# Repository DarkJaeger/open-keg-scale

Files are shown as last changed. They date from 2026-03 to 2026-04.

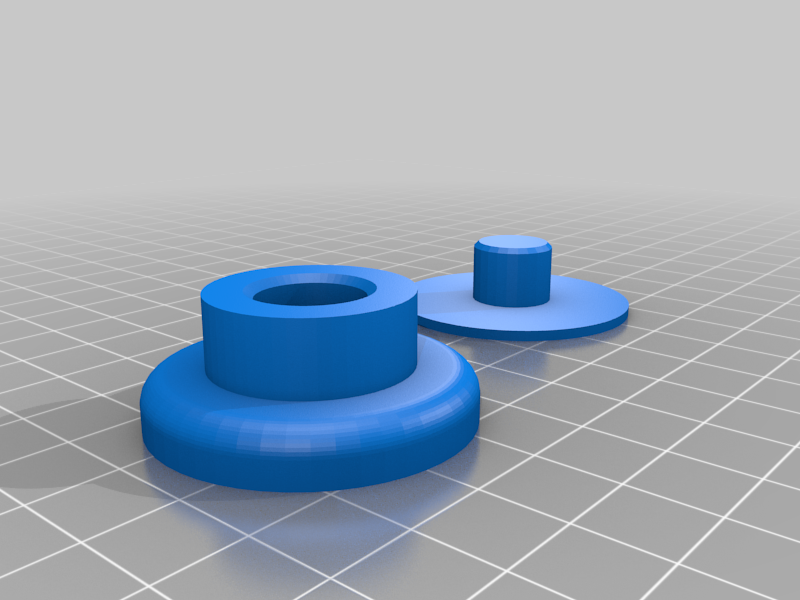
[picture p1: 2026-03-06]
open_keg_scale/3d printer files/images/16e5dbe0-ccde-49db-850b-022b4e718a14.png

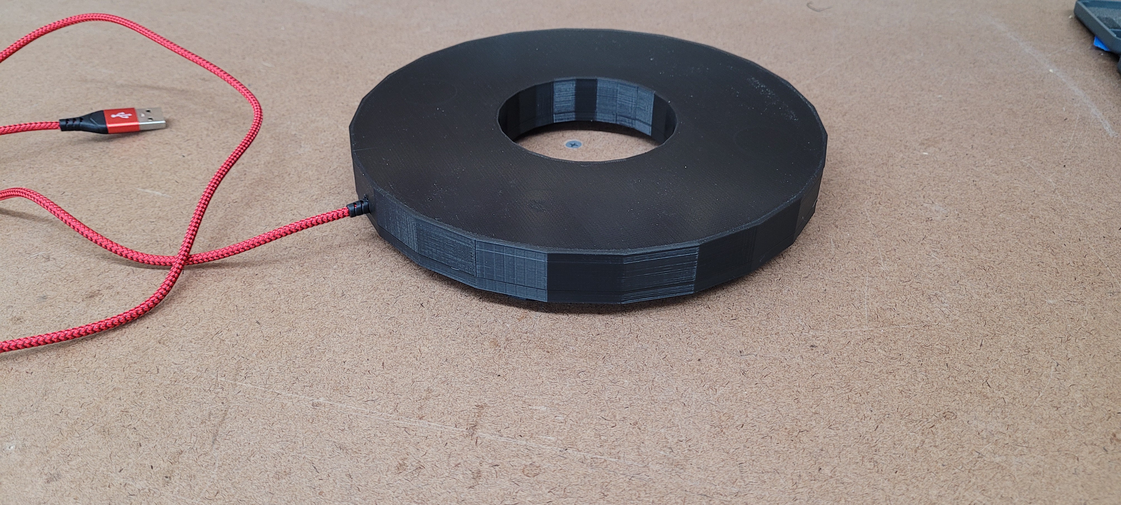
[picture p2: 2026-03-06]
open_keg_scale/3d printer files/images/8abd5797-2a0b-4ab6-b557-2e7c1733cc50.jpg

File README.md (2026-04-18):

<a href="https://www.buymeacoffee.com/LocutusOFB">Buy Me A Coffee</a>

🍺 Open Keg Scale

DIY WiFi-enabled keg scale hardware designed to work with
open-plaato-keg

This repo includes two complete scale designs:

🍻 Standard Keg Scale (serving / monitoring)
🔄 Transfer Keg Scale (closed-loop transfers)
🚀 Overview

Open Keg Scale provides real-time weight data from your kegs and feeds it into open-plaato-keg for:

Remaining volume tracking
Pour detection
Transfer monitoring
Usage analytics

All fully local — no cloud required.

⚖️ Scale Types
🍻 Standard Keg Scale (Serving)
6

Designed for kegerators and serving setups.

Use Cases:

Track remaining beer in keg
Monitor pours in real time
Integrate with dashboards / Home Assistant

Features:

Stable 4-load-cell platform
Continuous weight monitoring
Pour detection via weight delta
🔄 Transfer Keg Scale (Closed Transfer)
6

Designed for closed-loop transfers from fermenter → keg.

Use Cases:

Monitor fill progress during transfer
Prevent overfilling
Track exact transferred volume

Features:

Compact / targeted design
High accuracy for fill tracking
Real-time feedback during transfer
🧰 What’s Included
✅ STL files for both scale designs
✅ ESP32-based firmware examples
✅ Wiring guidance
✅ Integration with open-plaato-keg
🏗️ Hardware Requirements
ESP32 (recommended)
HX711 load cell amplifier
Load cells (typically 4x 50kg)
5V power supply
Optional OLED display
3D printed parts (included in /stl)
🖨️ 3D Printed Parts

All required STL files are included:

Standard scale platform
Transfer scale platform
Mounting hardware / enclosures

Print in PLA or PETG depending on environment

🔌 Wiring Overview
Load Cells → HX711
HX711 → ESP32 (DT + SCK)
Optional OLED → I2C
⚙️ Firmware

Recommended: ESPHome

sensor:
  - platform: hx711
    name: "Keg Weight"
    dout_pin: GPIO21
    clk_pin: GPIO22
    gain: 128
    update_interval: 1s
🔗 Integration

This hardware feeds data into:

👉 open-plaato-keg

Supports:

REST API
MQTT
Home Assistant bridge
📡 Data Flow
[Load Cells] → [HX711] → [ESP32] → [WiFi] → [open-plaato-keg]
⚖️ Calibration
Tare empty scale
Add known weight
Adjust calibration factor
Save configuration
🧪 Roadmap
 Auto-discovery in open-plaato-keg
 OTA updates
 Battery-powered version
 Multi-scale controller
🤝 Related Project
open-plaato-keg – backend + dashboard
💡 Pro Tips
Use 4 load cells for stability
Keep HX711 wiring short
Calibrate with realistic loads
Solid mounting = better accuracy

Corny keg scale (Plaato) by FloppyKnockers on Thingiverse: https://www.thingiverse.com/thing:6007574

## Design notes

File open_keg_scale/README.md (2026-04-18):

# Open Keg Scale – Firmware

Arduino sketch for **Wemos D1 Mini (ESP8266)** + **HX711** + **4 × 50 kg half-bridge load cells**.  
Reports keg weight / volume to [open-plaato-keg](https://github.com/DarkJaeger/open-plaato-keg) using the Blynk binary TCP protocol.
After the initial USB flash, it also supports **Arduino OTA** updates over WiFi.

---

## Parts

| Part | Notes |
|---|---|
| Wemos D1 Mini | ESP8266, 4 MB flash |
| HX711 breakout | Any common board |
| 4 × 50 kg half-bridge load cell | The ones that came with the scale |

---

## Wiring

### Load Cells → HX711

Wire the four half-bridge cells as a single **full Wheatstone bridge** for best accuracy.  
Each cell has three wires: **RED** (E+), **BLACK** (E−), **WHITE** (signal).

```
Cell A (front-left)   RED  ──┐
Cell B (front-right)  RED  ──┤──→  HX711 E+
Cell C (back-right)   RED  ──┤
Cell D (back-left)    RED  ──┘

Cell A (front-left)   BLACK──┐
Cell B (front-right)  BLACK──┤──→  HX711 E−
Cell C (back-right)   BLACK──┤
Cell D (back-left)    BLACK──┘

Cell A (front-left)   WHITE──┐
Cell C (back-right)   WHITE──┘──→  HX711 A+    (diagonal pair)

Cell B (front-right)  WHITE──┐
Cell D (back-left)    WHITE──┘──→  HX711 A−    (other diagonal pair)
```

> **Why diagonals?** Opposite corners of a platform scale flex in the same
> direction when loaded, so wiring them to the same signal leg produces
> additive output and cancels common-mode errors.

### HX711 → Wemos D1 Mini

| HX711 | Wemos D1 Mini |
|---|---|
| VCC | 3V3 |
| GND | GND |
| DT | D6 (GPIO 12)  |
| SCK | D5 (GPIO 14)  |

### Button / LED

| Signal | Pin |
|---|-----|
| Tare / reset button | D3 (GPIO 0) – built-in FLASH button |
| Status LED | D4 (GPIO 2) – built-in LED (active LOW) |

---

## LED Status

| Pattern | Meaning |
|---|---|
| Fast blink (100 ms) | Connecting to WiFi or Blynk server |
| Medium blink (250 ms) | TCP connected, waiting for auth |
| Slow blink (500 ms) | Fully connected and reporting |
| 3 short flashes | Tare complete |
| 4 short flashes | Calibration saved |

---

## Required Libraries

Install both via **Arduino IDE → Tools → Manage Libraries**:

| Library | Author | Version |
|---|---|---|
| **WiFiManager** | tzapu | ≥ 2.0.17 |
| **HX711 Arduino Library** | Bogdan Necula | ≥ 0.7.5 |

Board: **LOLIN(WEMOS) D1 mini** (under *ESP8266 Boards* – install ESP8266 core via Board Manager if needed).

`ArduinoOTA` comes with the ESP8266 board core, so there is no separate library to install for OTA updates.

---

## First-Time Setup

1. Flash `keg_scale.ino` to the Wemos D1 Mini.
2. On first boot the device creates a WiFi access point named **`KegScale-Setup`**.
3. Connect your phone/laptop to that AP (no password) and browse to `http://192.168.4.1`.
4. Fill in the form:
   - **WiFi SSID & password** – your home network
   - **Plaato Server Host** – IP or hostname of the machine running open-plaato-keg  
     (e.g. `192.168.1.50`)
   - **Server Port** – default `1234`
   - **Auth Token** – the 32-character hex token from the open-plaato-keg web UI
   - **Calibration Factor** – optional, if you already know the factor for this scale
   - **Max Keg Volume (L)** – e.g. `19` for a standard Cornelius keg
   - **Beer Name** – displayed in the UI
5. Click **Save**. The device reboots and connects automatically.

> To reconfigure, hold the FLASH button for **4+ seconds** – this wipes the
> saved WiFi credentials and restarts the setup portal.
> On enclosed units, you can also use the local web UI and click
> **Reset WiFi / Enter Setup Mode** to wipe credentials and return to
> `KegScale-Setup` without opening the enclosure.

---

## OTA Updates

After the board has been flashed once over USB and joined WiFi successfully, it will advertise an Arduino OTA target on your local network.

- **Hostname:** `keg-scale-<chipid>`
- **Password:** the same 32-character auth token configured for the server

In Arduino IDE:

1. Make sure your computer is on the same network as the keg scale.
2. Wait for the board to boot and connect to WiFi.
3. Open **Tools → Port** and choose the **network port** for `keg-scale-...`.
4. Click **Upload**.
5. When prompted, enter the auth token as the OTA password.

Serial output will show OTA status messages and progress during the update.

### Browser-based OTA

The firmware also serves a simple web page on the device IP:

- **Status page:** `http://<device-ip>/`
- **Firmware upload:** `http://<device-ip>/update`

If an auth token is configured, log in with:

- **Username:** `admin`
- **Password:** the same 32-character auth token

This is the simplest update path when Arduino IDE does not discover the board automatically over the network.

---

## Calibration

The scale ships with a calibration factor of `1.0` (uncalibrated). You must calibrate once before volume readings are accurate.

### Via the server UI (recommended)

1. Remove everything from the scale platform.
2. In the open-plaato-keg web interface, click **Tare**.
3. Place an object of known mass (e.g. a full water bottle, a bag of flour).
4. Enter the mass in **grams** in the *Calibrate with known weight* field and click **Send**.
5. The device saves the new calibration factor to flash.

### Via Serial

1. Open Serial Monitor at 115200 baud.
2. Remove everything from the scale and short-press the FLASH button to tare.
3. Place a known weight; note the raw reading printed on Serial.
4. Use the server UI calibrate command as above, or compute:  
   `cal_factor = raw_value / known_grams`

---

## Virtual Pin Reference

| Pin | Name | Direction | Description |
|-----|---|---|---|
| v48 | percent_of_beer_left | device → server | % of keg remaining |
| v49 | is_pouring | device → server | `"1"` while pouring |
| v51 | amount_left | device → server | Litres remaining |
| v53 | weight_raw | device → server | Total weight in grams |
| v54 | volume_raw | device → server | Liquid volume in L |
| v55 | pour_volume_raw | device → server | Last pour volume (L) |
| v59 | last_pour | device → server | Last pour volume (L) |
| v60 | tare | server → device | Send `"1"` to tare |
| v61 | known_weight_calibrate | server → device | Send grams to calibrate |
| v62 | empty_keg_weight | server → device | `"1"` = capture current; or send grams |
| v64 | beer_name | both | Beer name string |
| v71 | unit | server → device | `"1"`=metric `"2"`=US |
| v75 | measure_unit | server → device | `"1"`=weight `"2"`=volume |
| v76 | max_keg_volume | server → device | Max volume in litres |
| v81 | wifi_signal_strength | device → server | RSSI in dBm |
| v93 | firmware_version | device → server | e.g. `"1.0.0"` |

---

## Protocol Overview

The device speaks the **Blynk classic binary TCP protocol** (not Blynk IoT/v2).

```
Packet:   [cmd:u8][msg_id:u16be][length:u16be][body:bytes]
Response: [0x00  ][msg_id:u16be][status:u16be]            (no body)
```

1. Device connects TCP to `server_host:server_port`.
2. Sends **LOGIN** (cmd=2) with the auth token as body.
3. Server replies with a RESPONSE (status=200) using the same `msg_id`.
4. Device pushes data via **HARDWARE** (cmd=20) commands: body = `"vw\0<pin>\0<value>"`.
5. Device sends **PING** (cmd=6) every 30 s to keep the connection alive.
6. Server can push commands back to the device using HARDWARE write packets.

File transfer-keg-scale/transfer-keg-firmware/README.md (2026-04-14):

# Transfer Keg Firmware
**Platform:** Wemos D1 Mini (ESP8266)  
**Server:** open-plaato-server  
**Companion:** Android app via open-plaato API

---

## Wiring

### HX711 → D1 Mini
| HX711 | D1 Mini | GPIO  |
|---|---|---|
| DOUT  | D5 | 14 |
| SCK | D6 | 12 |
| VCC | 5V | — |
| GND | GND | — |

### OLED (SSD1306 128×64) → D1 Mini
| OLED | D1 Mini | GPIO |
|---|---|---|
| SDA  | D2 | 4 |
| SCL  | D1 | 5 |
| VCC  | 3.3V | — |
| GND  | GND | — |

### Load Cells → HX711
Wire 4 cells as a Wheatstone bridge:
```
Cell A: E+ → E+,  S+ → A+
Cell B: E+ → E+,  S+ → B+   (opposite corner to A)
Cell C: E- → E-,  S- → A-
Cell D: E- → E-,  S- → B-   (opposite corner to C)
```
Most 4-cell platform kits include a combinator PCB — use that if available.

---

## Quick Start

### 1. Edit `src/main.cpp` config block
```cpp
#define WIFI_SSID       "YourSSID"
#define WIFI_PASSWORD   "YourPassword"
#define SERVER_BASE_URL "http://192.168.1.100:3000"
#define SCALE_ID        "scale1"
#define CALIBRATION_FACTOR  -430.0f   // find with calibration sketch
#define DEFAULT_EMPTY_KG    3.8f
#define DEFAULT_TARGET_KG   12.5f
```

### 2. Find your calibration factor
1. Rename `calibration.cpp.txt` → `calibration.cpp` (comment out main.cpp)
2. Flash, open Serial Monitor @ 115200
3. Follow prompts with a known weight (e.g. 10 kg)
4. Copy printed `CALIBRATION_FACTOR` back into `main.cpp`
5. Restore `main.cpp` as main entry point

### 3. Flash
```bash
pio run -t upload
pio device monitor
```

---

## API Contract

### POST `/api/transfer-scales/:id`
Sent every 5 seconds (configurable via `POST_INTERVAL_MS`).

**Request body:**
```json
{
  "weight": 8.42,
  "unit": "kg",
  "emptyWeight": 3.8,
  "targetWeight": 12.5
}
```

### GET `/api/transfer-scales/:id`
Polled every 30 seconds. Used to sync `emptyWeight` / `targetWeight` from server.

**Expected response (200 OK):**
```json
{
  "emptyWeight": 3.8,
  "targetWeight": 12.5
}
```
Any field absent from the response is silently ignored (device keeps its current value).

---

## OLED Layout
```
┌────────────────────────┐
│ TRANSFER SCALE  [W]    │  ← [W] = WiFi connected, [ ] = offline
│                        │
│   8.42 kg              │  ← large text (TextSize 2)
│   ████████░░  67%      │  ← progress bar (net weight / net target)
│                        │
│ Tgt:12.5kg  Emp: 3.8   │  ← target / empty keg weight
└────────────────────────┘
```

Progress % = `(currentWeight - emptyWeight) / (targetWeight - emptyWeight)`

---

## Serial Commands (115200 baud)
| Key | Action |
|-----|---|
| `t` | Tare (zero) the scale |
| `+` | Increase calibration factor by 10 |
| `-` | Decrease calibration factor by 10 |
| `r` | Print raw HX711 reading |
| `c` | Print current calibration factor |
| `?` | Show help |

---

## Calibration Notes
- The bogde HX711 library `get_units()` divides by the calibration factor, so:
  - `calFactor = raw_reading / known_weight_kg`
  - If readings are inverted (negative), negate the factor
- `scale.tare()` is called at boot — ensure nothing is on the platform at power-on
- Temperature drift: re-tare after the load cell warms up (~5 min)

---

## Troubleshooting
| Symptom | Fix |
|---|-----|
| OLED blank | Check I2C address (try `0x3C` or `0x3D`); run I2C scanner |
| HX711 ERROR on boot | Check DOUT/SCK wiring; ensure 5V supply to HX711 |
| Weight reads ~0 always | Calibration factor wrong; re-run calibration sketch |
| Weight oscillates wildly | Mechanical issue with load cell mounting; check cell corners are free |
| POST fails silently | Check SERVER_BASE_URL; ensure device and server on same network |
| WiFi never connects | Check credentials; D1 Mini is 2.4 GHz only |

---

## Dependencies (`platformio.ini`)
```
bogde/HX711 @ ^0.7.5
adafruit/Adafruit SSD1306 @ ^2.5.7
adafruit/Adafruit GFX Library @ ^1.11.9
adafruit/Adafruit BusIO @ ^1.14.5
```
All resolved automatically by PlatformIO.

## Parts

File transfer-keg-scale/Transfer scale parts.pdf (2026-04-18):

Controller (WiFi + logic)
Wemos D1 Mini ESP8266
$1.34
•
AliExpress + others
ESP8266-based, Arduino compatible
Built-in WiFi (perfect for your automation setup) Small footprint for enclosure builds
3.3V logic (important for HX711 + OLED)
Load Measurement System
Load Cells (x4)
4x 50kg Half-Bridge Load Cells
$14.70
•
eBay - williaalfar7
Each: 50kg → combined scale ≈ 200kg capacity Half-bridge → MUST wire all 4 together Standard bathroom-scale style configuration Amplifier (Required)
HX711 Load Cell Amplifier
$7.80
•
Display
1.3" SH1106 I2C OLED Display $9.55
•
Addicore
128×64 resolution
I2C (only 2 wires: SDA + SCL) Works great with ESP8266 libraries User Input (Tare / Start Button) 7mm Momentary Push Button (SPST) $6.73
•
Harfington
Normally open (perfect for GPIO input) Use internal pull-up on ESP8266

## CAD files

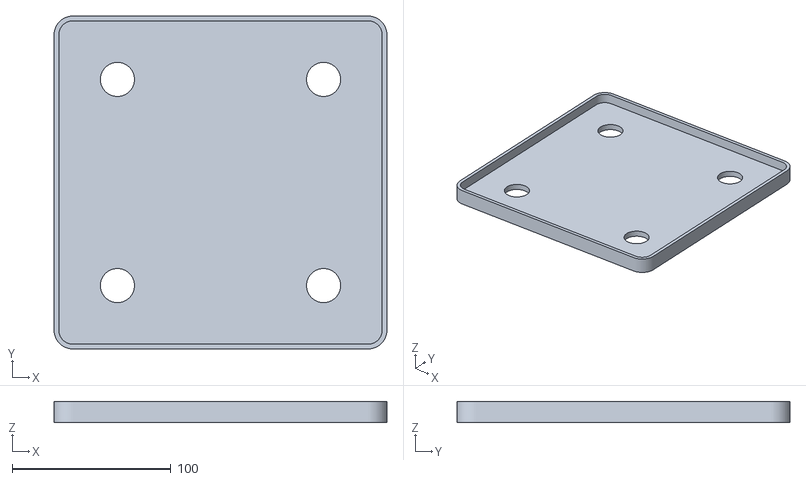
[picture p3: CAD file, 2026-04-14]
open_keg_scale/3d printer files/files/keg_scale_bottom_cover.stl
210.0 x 210.0 x 13.2

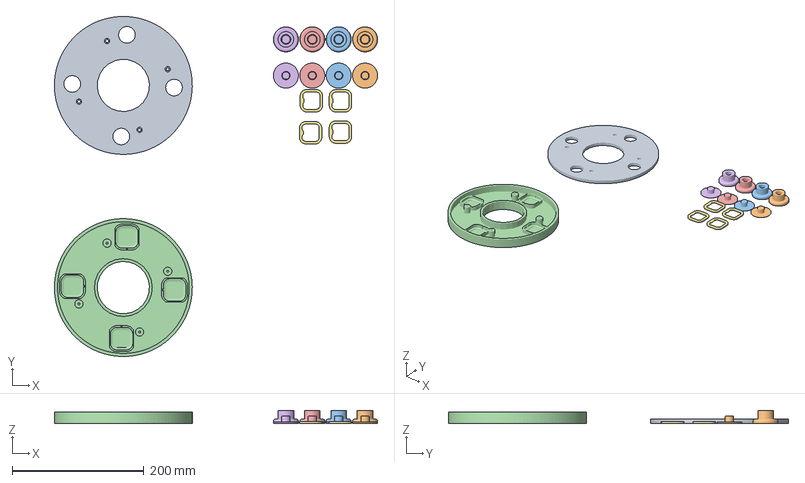
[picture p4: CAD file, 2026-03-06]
open_keg_scale/3d printer files/Keg Scale for Ball Lock Kegs.3mf
491.2 x 516.7 x 19.0 mm
Bottom_BallLock100sided.stl
feets_new.stl x 4
Top_BallLock100sided.stl
Load_cell_clip_4.stl

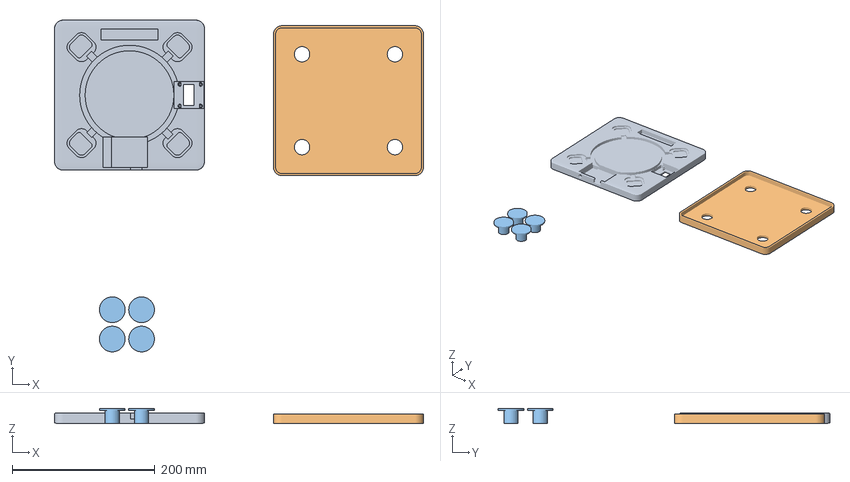
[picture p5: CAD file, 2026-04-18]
transfer-keg-scale/transfer scale.3mf
516.5 x 464.4 x 21.0 mm
BrewKegLevelScales.stl
keg_scale_bottom_cover.stl
keg_scale_feet.stl

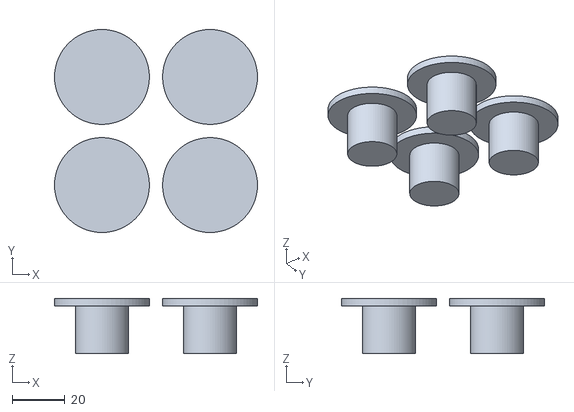
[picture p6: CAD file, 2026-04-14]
open_keg_scale/3d printer files/files/keg_scale_feet.stl
77.0 x 77.0 x 21.0

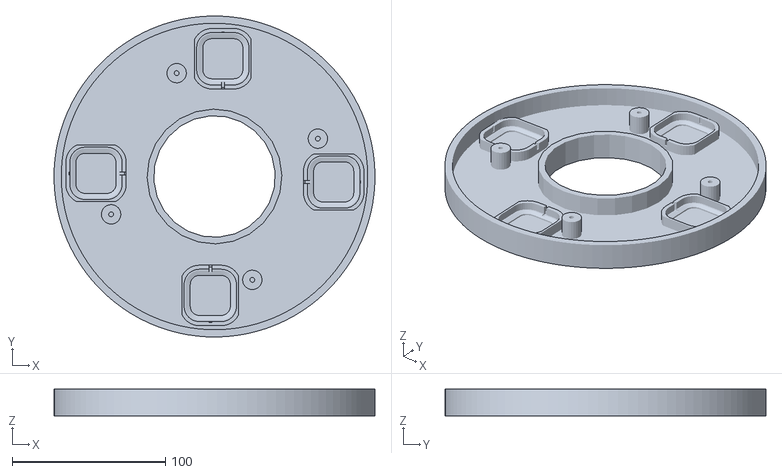
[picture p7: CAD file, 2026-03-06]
open_keg_scale/3d printer files/files/Top_BallLock100sided.stl
209.5 x 209.5 x 17.5

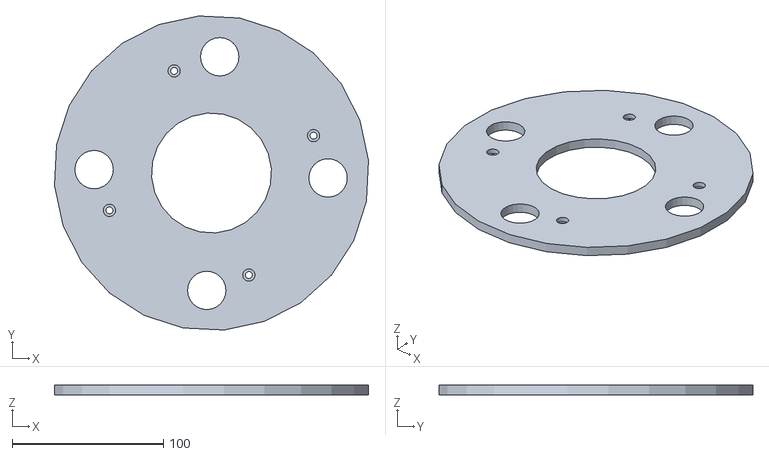
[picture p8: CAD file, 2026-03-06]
open_keg_scale/3d printer files/files/Bottom_fixed.stl
207.6 x 207.6 x 6.35

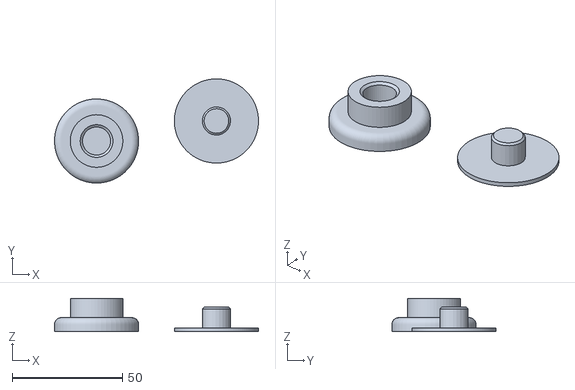
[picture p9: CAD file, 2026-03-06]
open_keg_scale/3d printer files/files/feetshort.stl
92.3 x 47.2 x 15.1

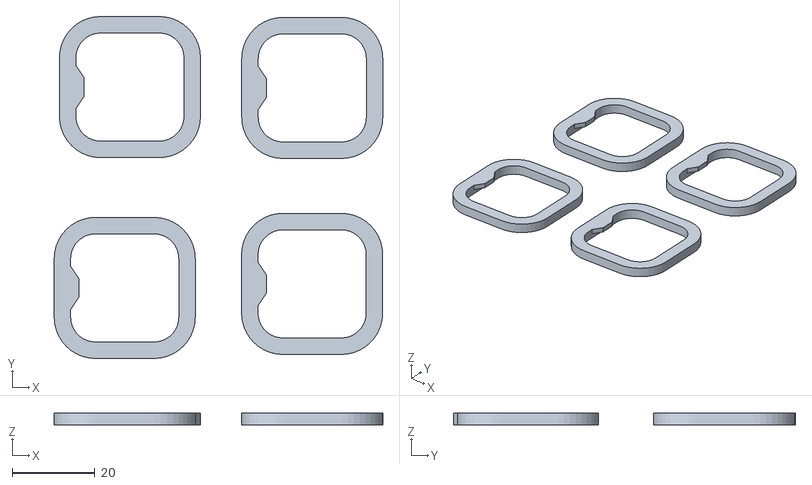
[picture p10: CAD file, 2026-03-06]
open_keg_scale/3d printer files/files/Load_cell_clip_4.stl
79.7 x 82.9 x 3.00

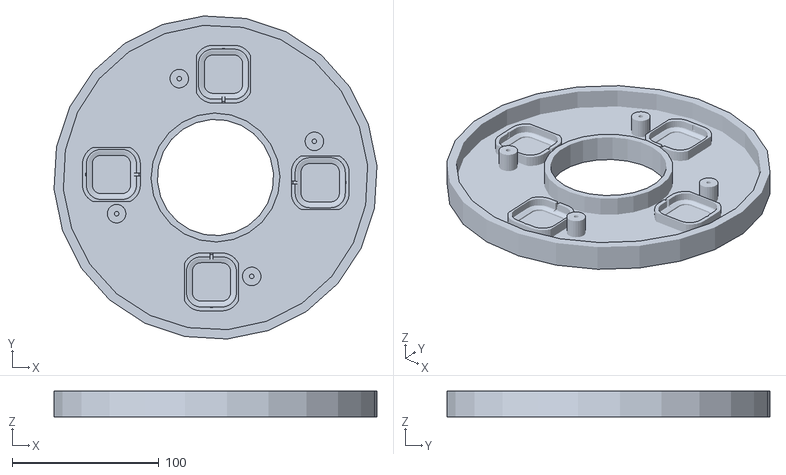
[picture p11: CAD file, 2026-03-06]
open_keg_scale/3d printer files/files/Toppinlock2.stl
220.4 x 220.4 x 17.5

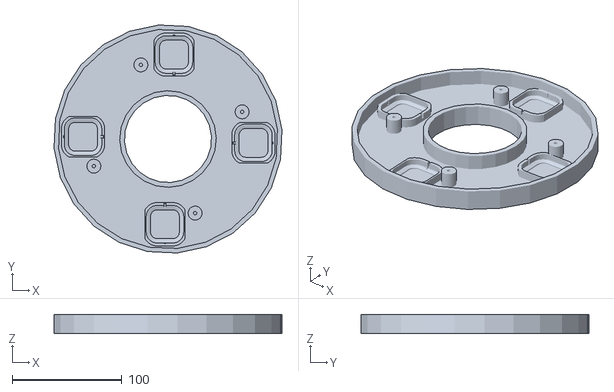
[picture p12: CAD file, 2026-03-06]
open_keg_scale/3d printer files/files/Topedit_fixed.stl
207.6 x 207.6 x 17.5

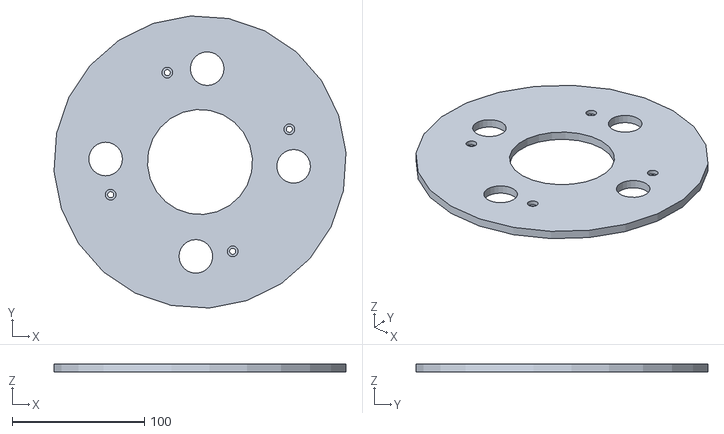
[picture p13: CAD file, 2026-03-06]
open_keg_scale/3d printer files/files/BottomPinlock2.stl
220.5 x 220.5 x 6.35

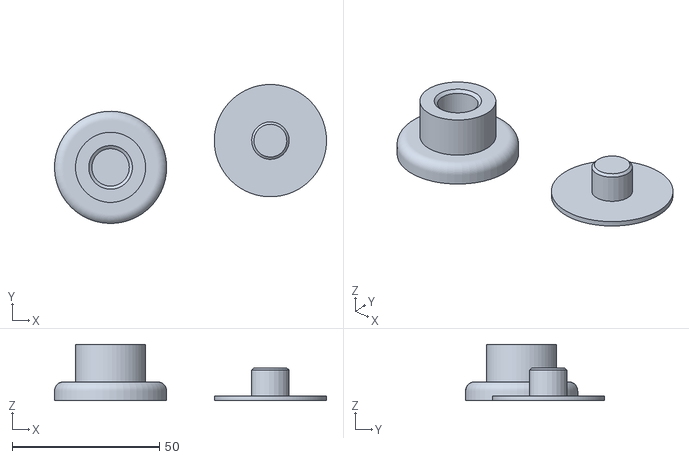
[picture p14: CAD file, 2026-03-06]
open_keg_scale/3d printer files/files/feets_new.stl
92.3 x 47.2 x 19.0

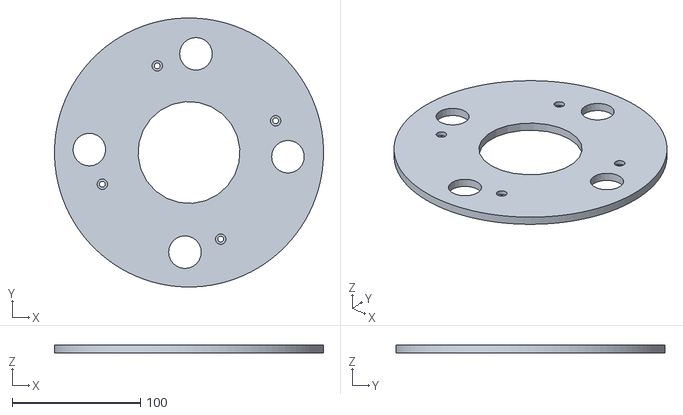
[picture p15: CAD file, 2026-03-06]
open_keg_scale/3d printer files/files/Bottom_BallLock100sided.stl
209.5 x 209.5 x 6.35

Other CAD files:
open_keg_scale/3d printer files/files/Bottom_hole_edit.skp
open_keg_scale/3d printer files/files/KegScale.skp
open_keg_scale/3d printer files/files/KegScaleedit.skp
open_keg_scale/3d printer files/files/KegScaleedit_1.skp
open_keg_scale/3d printer files/files/KegScaleedit_2.skp
open_keg_scale/3d printer files/files/Top-bottom_pinlock.skp
open_keg_scale/3d printer files/files/Top2.skp
open_keg_scale/3d printer files/files/feetnew.skp
open_keg_scale/3d printer files/files/feetshort.skp

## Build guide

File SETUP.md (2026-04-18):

# Setup Guide – Open Keg Scale & Transfer Keg Scale

Both projects use a **Wemos D1 Mini (ESP8266)** with an **HX711** ADC and **4 × 50 kg half-bridge load cells**.  
Choose the project that fits your needs:

| | Open Keg Scale | Transfer Keg Scale |
|---|---|---|
| **Display** | Web dashboard (open-plaato-keg server) | Local OLED 128×64 |
| **Protocol** | Blynk binary TCP | HTTP REST API |
| **Build tool** | Arduino IDE | PlatformIO |
| **Use case** | Permanent tap monitoring | Portable / transfer use |

---

## Table of Contents

1. [Hardware & Parts](#1-hardware--parts)
2. [Wiring](#2-wiring)
3. [Open Keg Scale – Software Setup](#3-open-keg-scale--software-setup)
4. [Open Keg Scale – First-Time Device Setup](#4-open-keg-scale--first-time-device-setup)
5. [Open Keg Scale – Calibration](#5-open-keg-scale--calibration)
6. [Open Keg Scale – OTA Updates](#6-open-keg-scale--ota-updates)
7. [Transfer Keg Scale – Software Setup](#7-transfer-keg-scale--software-setup)
8. [Transfer Keg Scale – First-Time Device Setup](#8-transfer-keg-scale--first-time-device-setup)
9. [Transfer Keg Scale – Calibration](#9-transfer-keg-scale--calibration)
10. [Troubleshooting](#10-troubleshooting)

---

## 1. Hardware & Parts

### Shared (both projects)

| Part | Notes |
|---|---|
| Wemos D1 Mini | ESP8266, 4 MB flash — **2.4 GHz WiFi only** |
| HX711 breakout | Any common board; 24-bit ADC |
| 4 × 50 kg half-bridge load cell | RED / BLACK / WHITE 3-wire cells |
| Micro-USB cable | For initial flash |
| 5 V USB power supply | ≥ 500 mA |

### Transfer Keg Scale only

| Part | Notes |
|---|---|
| OLED 128×64 | SSD1306 or SH1106, I2C, 4-pin (VCC / GND / SDA / SCL) |

### Optional

| Part | Notes |
|---|---|
| Load cell combinator PCB | Simplifies the Wheatstone bridge wiring |
| 3D-printed enclosure | STL files in `open_keg_scale/3d printer files/` (Open Keg Scale), `transfer-keg-scale/transfer scale.3mf` (Transfer) |

---

## 2. Wiring

Both projects share the same **load cell → HX711** wiring.  
Refer to the `Wiring info.jpg` in each project folder for a visual diagram.

### 2a. Load Cells → HX711 (Wheatstone Bridge)

Wire the four half-bridge cells as one full bridge.  
Each cell has three wires: **RED** (excitation +), **BLACK** (excitation −), **WHITE** (signal).

```
Cell A (front-left)   RED  ──┐
Cell B (front-right)  RED  ──┤──→  HX711 E+
Cell C (back-right)   RED  ──┤
Cell D (back-left)    RED  ──┘

Cell A (front-left)   BLACK──┐
Cell B (front-right)  BLACK──┤──→  HX711 E−
Cell C (back-right)   BLACK──┤
Cell D (back-left)    BLACK──┘

Cell A (front-left)   WHITE──┐
Cell C (back-right)   WHITE──┘──→  HX711 A+   (diagonal pair)

Cell B (front-right)  WHITE──┐
Cell D (back-left)    WHITE──┘──→  HX711 A−   (opposite diagonal pair)
```

> **Why diagonals?** Opposite platform corners flex the same direction under load.
> Wiring them to the same signal leg gives additive output and cancels common-mode errors.

If your kit included a **combinator PCB**, wire each cell's three leads to it and connect the PCB's four output lines (E+, E−, A+, A−) directly to the HX711.

### 2b. HX711 → Wemos D1 Mini

#### Open Keg Scale

| HX711 | D1 Mini pin | GPIO |
|---|---|---|
| VCC | 3V3 | — |
| GND | GND | — |
| DT | D6 | 12 |
| SCK | D5 | 14 |

#### Transfer Keg Scale

| HX711 | D1 Mini pin | GPIO |
|---|---|---|
| VCC | 5V | — |
| GND | GND | — |
| DOUT  | D5 | 14 |
| SCK | D6 | 12 |

> The Transfer Keg Scale powers the HX711 from **5 V** for better noise immunity.

### 2c. OLED → D1 Mini (Transfer Keg Scale only)

| OLED | D1 Mini pin | GPIO |
|---|---|---|
| VCC  | 3V3 | — |
| GND  | GND | — |
| SDA  | D2 | 4 |
| SCL  | D1 | 5 |

### 2d. Buttons & LED (Open Keg Scale)

| Signal | Pin |
|---|-----|
| Tare / reset button | D3 (GPIO 0) — built-in FLASH button |
| Status LED | D4 (GPIO 2) — built-in LED, active LOW |

---

## 3. Open Keg Scale – Software Setup

### 3a. Install Arduino IDE

Download and install **Arduino IDE 2.x** from [arduino.cc](https://www.arduino.cc/en/software).

### 3b. Add ESP8266 Board Support

1. Open **File → Preferences**.
2. In *Additional boards manager URLs* add:
   ```
   https://arduino.esp8266.com/stable/package_esp8266com_index.json
   ```
3. Open **Tools → Board → Boards Manager**, search **esp8266**, install the **esp8266 by ESP8266 Community** package.

### 3c. Select the Board

**Tools → Board → ESP8266 Boards → LOLIN(WEMOS) D1 mini**

Recommended upload settings:
- Upload Speed: `921600`
- CPU Frequency: `80 MHz`
- Flash Size: `4MB (FS:2MB OTA:~1019KB)`

### 3d. Install Libraries

**Tools → Manage Libraries**, search and install:

| Library | Author | Minimum version |
|---|---|---|
| WiFiManager | tzapu | 2.0.17 |
| HX711 Arduino Library | Bogdan Necula | 0.7.5 |

`ArduinoOTA` ships with the ESP8266 core — no separate install needed.

### 3e. Flash the Firmware

1. Connect the D1 Mini via USB.
2. Open `open_keg_scale/keg_scale.ino` in Arduino IDE.
3. Select the correct **Port** under **Tools → Port**.
4. Click **Upload** (Ctrl+U).

---

## 4. Open Keg Scale – First-Time Device Setup

After the first flash the device has no WiFi credentials and boots into **setup mode** automatically.

1. On your phone or laptop, scan for WiFi networks. Connect to **`KegScale-Setup`** (no password).
2. A captive portal will open automatically, or browse to `http://192.168.4.1`.
3. Fill in all fields and click **Save**:

| Field | Description |
|---|---|
| WiFi SSID | Your 2.4 GHz network name |
| WiFi Password | Your network password |
| Plaato Server Host | IP or hostname of the machine running [open-plaato-keg](https://github.com/DarkJaeger/open-plaato-keg) (e.g. `192.168.1.50`) |
| Server Port | Default `1234` |
| Auth Token | 32-character hex token from the open-plaato-keg web UI |
| Calibration Factor | Leave blank on first setup; calibrate after mounting the scale |
| Max Keg Volume (L) | `19` for a standard Cornelius / ball-lock keg |
| Beer Name | Displayed in the dashboard |

4. The device reboots, connects to your WiFi, then connects to the Plaato server.  
   The LED will slow-blink (500 ms) once fully connected and reporting.

> **Re-enter setup mode at any time:**  
> Hold the FLASH button for **4+ seconds** to wipe credentials, or use the web UI at  
> `http://<device-ip>/` → **Reset WiFi / Enter Setup Mode**.

### LED Status Reference

| Pattern | Meaning |
|---|---|
| Fast blink (100 ms) | Connecting to WiFi or server |
| Medium blink (250 ms) | TCP connected, waiting for auth |
| Slow blink (500 ms) | Fully connected and reporting |
| 3 short flashes | Tare complete |
| 4 short flashes | Calibration saved |

---

## 5. Open Keg Scale – Calibration

The scale ships with a calibration factor of `1.0` (uncalibrated). Calibrate once after physically mounting the load cells.

### Via the server UI (recommended)

1. Remove everything from the scale platform.
2. In the open-plaato-keg web interface, click **Tare**.
3. Place a known-weight object (e.g. a full keg, a bag of flour, a filled water container).
4. Enter its mass in **grams** in the *Calibrate with known weight* field and click **Send**.
5. The device saves the calibration factor to flash.

### Via Serial Monitor

1. Open **Tools → Serial Monitor** at `115200` baud.
2. Clear the platform and short-press the FLASH button to tare.
3. Place a known weight; note the raw ADC value printed.
4. Compute: `calibration_factor = raw_value / known_grams`
5. Enter the factor via the server UI calibrate command or web UI.

---

## 6. Open Keg Scale – OTA Updates

After the initial USB flash and WiFi join, the device advertises an Arduino OTA target.

### Via Arduino IDE

1. Ensure your computer and the device are on the same network.
2. Wait for the device to connect (slow LED blink).
3. **Tools → Port** → choose the **network port** for `keg-scale-<chipid>`.
4. Click **Upload**. When prompted for a password enter the **32-character auth token**.

### Via Web UI (easiest)

Browse to `http://<device-ip>/update`, log in with:
- **Username:** `admin`
- **Password:** your 32-character auth token

Upload the compiled `.bin` file directly.

---

## 7. Transfer Keg Scale – Software Setup

### 7a. Install PlatformIO

Install [Visual Studio Code](https://code.visualstudio.com/) then add the **PlatformIO IDE** extension from the Extensions Marketplace.

Alternatively install the PlatformIO CLI:
```bash
pip install platformio
```

### 7b. Open the Project

Open the folder `transfer-keg-scale/transfer-keg-firmware/` in VS Code.  
PlatformIO will automatically resolve all library dependencies listed in `platformio.ini` on the first build.

### 7c. Configure `src/main.cpp`

Edit the config block near the top of `src/main.cpp`:

```cpp
#define WIFI_SSID           "YourSSID"
#define WIFI_PASSWORD       "YourPassword"
#define SERVER_BASE_URL     "http://192.168.1.100:3000"   // open-plaato-server address
#define SCALE_ID            "scale1"                       // unique ID for this scale
#define CALIBRATION_FACTOR  -430.0f   // replace after running calibration sketch
#define DEFAULT_EMPTY_KG    3.8f      // weight of your empty keg in kg
#define DEFAULT_TARGET_KG   12.5f     // weight of a full keg in kg
```

> Set `DEFAULT_EMPTY_KG` and `DEFAULT_TARGET_KG` for your keg type.  
> A standard 19 L Cornelius keg weighs ~4 kg empty and ~23 kg full.

### 7d. Flash the Firmware

#### Option A – Pre-compiled binary (quickest)

Use `esptool.py` or the [ESP8266 Flash Download Tool](https://www.espressif.com/en/support/download/other-tools) to flash `transfer-keg-scale/firmware.bin` at address `0x0`.

```bash
esptool.py --port COM3 write_flash 0x0 transfer-keg-scale/firmware.bin
```

#### Option B – Build from source (PlatformIO)

```bash
cd transfer-keg-scale/transfer-keg-firmware
pio run -t upload
```

---

## 8. Transfer Keg Scale – First-Time Device Setup

1. Power the device. The OLED shows **"TRANSFER SCALE"** with no WiFi indicator.
2. Connect your phone or laptop to the WiFi AP **`TransferScale-Setup`** (password: `scaleme`).
3. Browse to `http://192.168.4.1`.
4. Fill in the setup portal:

| Field | Description |
|---|---|
| WiFi SSID | Your 2.4 GHz network name |
| WiFi Password | Your network password |
| Server Base URL | Full URL to open-plaato-server (e.g. `http://192.168.1.100:3000`) |
| Scale ID | Unique identifier (e.g. `transfer1`) |
| Calibration Factor | From calibration sketch (Step 9); leave default for now |
| Empty Keg Weight (kg) | Weight of your empty keg |
| Target Weight (kg) | Weight of a full keg |

5. Click **Save**. The device reboots, connects to WiFi, and the OLED shows **[W]** when connected.

> **Re-enter setup mode:** Hold the FLASH button (D3) for **3+ seconds**.

### OLED Display Layout

```
┌────────────────────────┐
│ TRANSFER SCALE  [W]    │  ← [W] = WiFi connected
│                        │
│   8.42 kg              │  ← current weight (large text)
│   ████████░░  67%      │  ← fill progress bar
│                        │
│ Tgt:12.5kg  Emp: 3.8   │  ← target / empty weights
└────────────────────────┘
```

Progress % = `(currentWeight − emptyWeight) / (targetWeight − emptyWeight) × 100`

---

## 9. Transfer Keg Scale – Calibration

### Via Calibration Sketch

1. In `transfer-keg-scale/transfer-keg-firmware/src/`, rename:
   ```
   calibration.cpp.txt  →  calibration.cpp
   ```
2. In `platformio.ini`, comment out the `main.cpp` build source and uncomment `calibration.cpp` (or temporarily exclude `main.cpp` from compilation).
3. Flash and open Serial Monitor at `115200` baud:
   ```bash
   pio device monitor
   ```
4. Follow the on-screen prompts:
   - Remove everything from the platform when asked.
   - Place a **known weight** (e.g. a 10 kg object) when prompted.
   - The sketch prints `CALIBRATION_FACTOR = -430.5` (example).
5. Copy that value back into the `#define CALIBRATION_FACTOR` line in `main.cpp`.
6. Undo the `platformio.ini` changes, rename `calibration.cpp` back to `calibration.cpp.txt`, and re-flash `main.cpp`.

### Via Serial Commands (quick adjustment)

With `main.cpp` running, open Serial Monitor at `115200` baud:

| Key | Action |
|-----|---|
| `t` | Tare (zero) the scale |
| `+` | Increase calibration factor by 10 |
| `-` | Decrease calibration factor by 10 |
| `r` | Print raw HX711 reading |
| `c` | Print current calibration factor |
| `?` | Show help |

Use `+` / `−` to nudge the factor until a known weight reads correctly, then save the final value to `main.cpp` and re-flash.

### Calibration Notes

- If readings are **negative**, negate the calibration factor.
- `scale.tare()` runs at boot — keep the platform **empty at power-on**.
- Re-tare after ~5 minutes to account for load cell thermal warm-up.

---

## 10. Troubleshooting

### Open Keg Scale

| Symptom | Fix |
|---|-----|
| No `KegScale-Setup` AP appears | Hold FLASH button 4 s to wipe credentials and restart setup |
| LED stuck fast-blinking | Device cannot reach WiFi or Plaato server; check credentials and server IP |
| Weight always 0 or garbage | Check HX711 DT→D6, SCK→D5 wiring; verify 3V3 supply |
| OTA port not visible in IDE | Ensure device and PC are on the same subnet; firewall may block mDNS |
| Volume reads wrong after calibration | Re-tare with empty platform, then re-calibrate with known weight |

### Transfer Keg Scale

| Symptom | Fix |
|---|-----|
| OLED stays blank | Check I2C address — try `0x3C` then `0x3D`; verify SDA→D2, SCL→D1 |
| `HX711 ERROR` on boot | Check DOUT→D5, SCK→D6; confirm 5 V supply to HX711 |
| Weight reads ~0 always | Calibration factor is wrong — re-run calibration sketch |
| Weight oscillates wildly | Load cell mounting issue; ensure cell corners move freely and aren't over-constrained |
| POST to server fails | Check `SERVER_BASE_URL`; device and server must be on the same network |
| WiFi never connects | Confirm 2.4 GHz SSID; D1 Mini does not support 5 GHz |
| No `[W]` on OLED after setup | Wrong SSID/password; hold FLASH 3 s to re-enter setup portal |

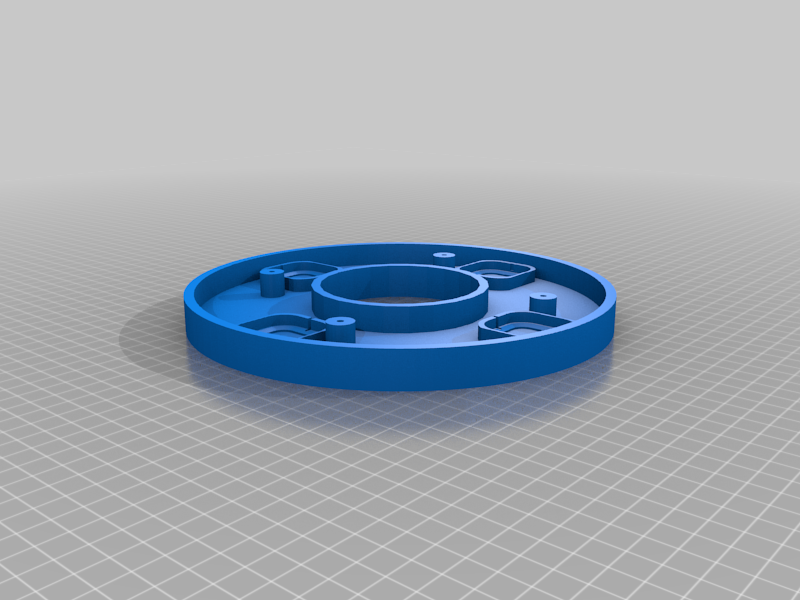
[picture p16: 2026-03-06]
open_keg_scale/3d printer files/images/ba72c7f0-80f5-45ed-a590-08b309b3ebf0.png

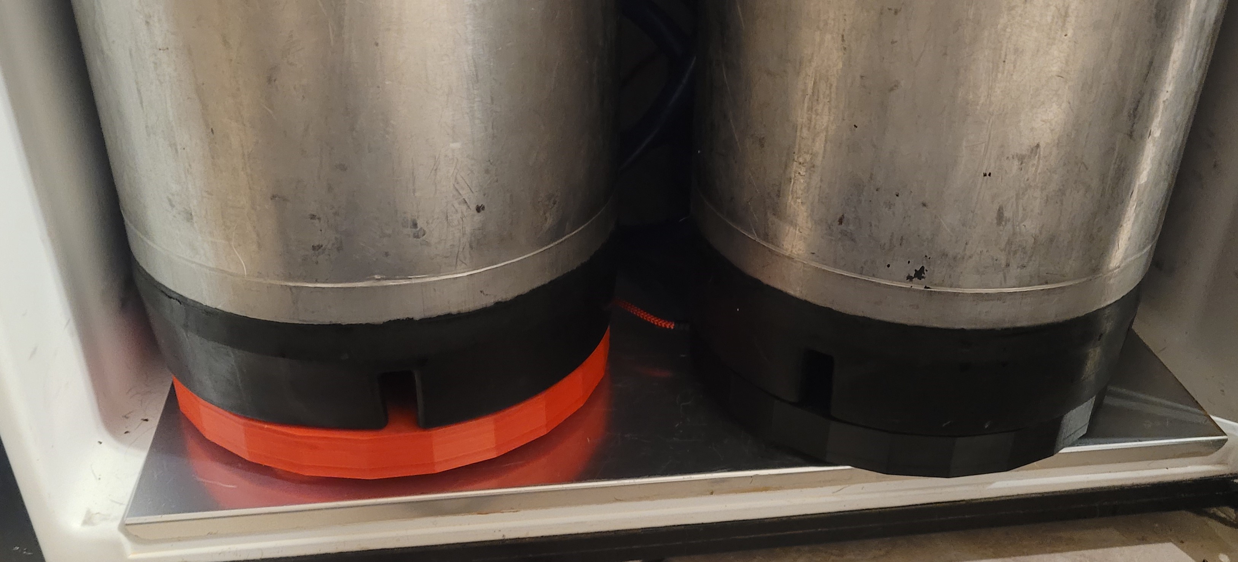
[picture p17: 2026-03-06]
open_keg_scale/3d printer files/images/19ec35dc-2142-4d12-ba8d-c374caf3b63c.jpg

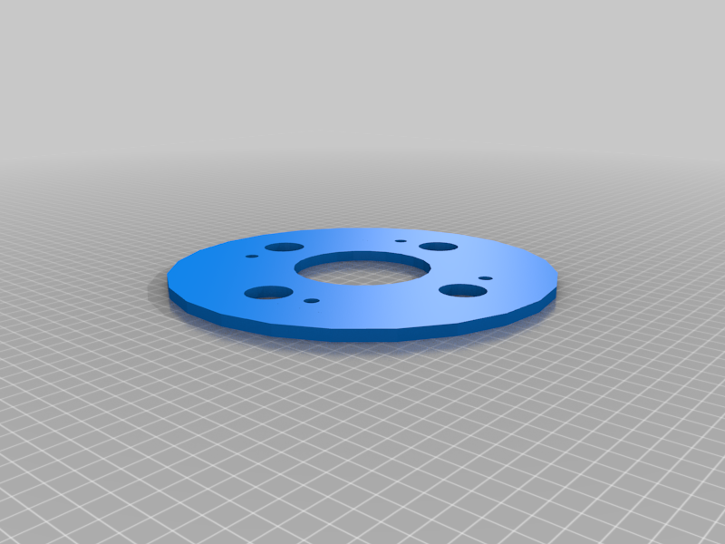
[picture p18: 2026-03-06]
open_keg_scale/3d printer files/images/b01a53bb-e53e-47a2-aeae-218e56c87f92.png

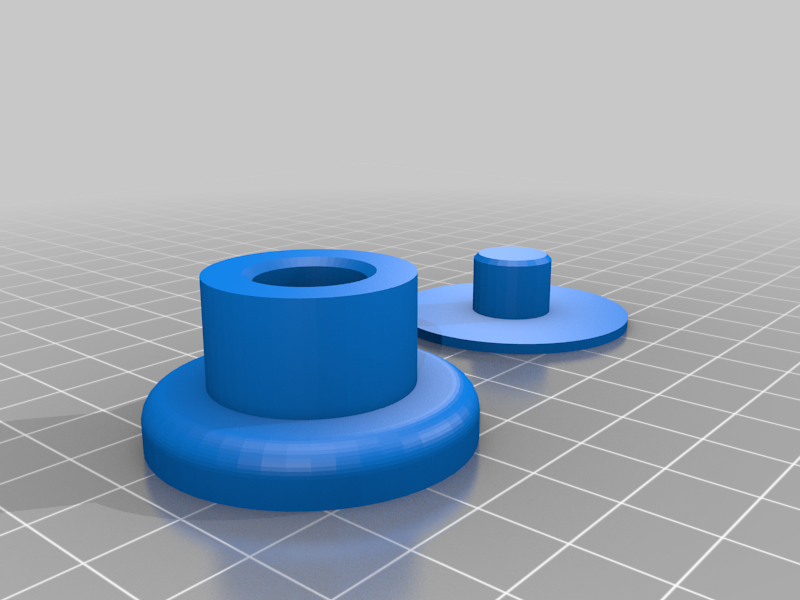
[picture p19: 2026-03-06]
open_keg_scale/3d printer files/images/3b3f8c57-7d05-451e-be07-a448e9eacfb0.png

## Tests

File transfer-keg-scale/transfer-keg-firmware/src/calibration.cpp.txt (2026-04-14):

/*
 * HX711 Calibration Sketch for D1 Mini
 * ─────────────────────────────────────
 * 1. Flash this sketch
 * 2. Open Serial Monitor @ 115200
 * 3. Follow prompts — place known weight when asked
 * 4. Note the printed CALIBRATION_FACTOR
 * 5. Paste it into main.cpp → CALIBRATION_FACTOR
 *
 * Wiring:
 *   HX711 DOUT → D5 (GPIO14)
 *   HX711 SCK  → D6 (GPIO12)
 */

#include <Arduino.h>
#include <HX711.h>

#define DOUT_PIN 14
#define SCK_PIN  12
#define KNOWN_WEIGHT_KG 10.0f   // ← change to your calibration weight

HX711 scale;

void setup() {
    Serial.begin(115200);
    delay(500);

    Serial.println("\n=== HX711 Calibration ===");
    Serial.println("Make sure nothing is on the scale.");
    Serial.println("Press ENTER to tare...");
    while (!Serial.available()) { yield(); }
    while (Serial.available()) Serial.read();

    scale.begin(DOUT_PIN, SCK_PIN);
    scale.tare(20);
    Serial.println("Tared.");

    Serial.printf("Now place %.1f kg on the scale.\n", KNOWN_WEIGHT_KG);
    Serial.println("Press ENTER when ready...");
    while (!Serial.available()) { yield(); }
    while (Serial.available()) Serial.read();

    long raw = scale.get_value(20);
    float calFactor = (float)raw / KNOWN_WEIGHT_KG;

    Serial.printf("\nRaw reading:         %ld\n", raw);
    Serial.printf("Calibration factor:  %.2f\n", calFactor);
    Serial.printf("\nPaste into main.cpp:\n  #define CALIBRATION_FACTOR  %.2ff\n", calFactor);

    // Verify
    scale.set_scale(calFactor);
    Serial.println("\nVerification (should read close to known weight):");
    for (int i = 0; i < 5; i++) {
        Serial.printf("  %.3f kg\n", scale.get_units(10));
        delay(500);
    }
}

void loop() {
    scale.set_scale(scale.get_scale());  // keep reading
    Serial.printf("Live: %.3f kg  (cal=%.2f)\n",
                  scale.get_units(5), scale.get_scale());
    delay(800);
}

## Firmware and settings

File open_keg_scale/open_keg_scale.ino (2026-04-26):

/*
 * Open Keg Scale Firmware v1.0.0
 * ================================
 * Hardware : Wemos D1 Mini (ESP8266) + HX711 + 4x 50 kg Half-Bridge Load Cells
 * Server   : open-plaato-keg  (https://github.com/DarkJaeger/open-plaato-keg)
 * Protocol : Blynk binary TCP (port 1234 by default)
 *
 * ── Load Cell Wiring (4x Half-Bridge → 1 Full Wheatstone Bridge) ─────────────
 *
 *   This build uses the common bathroom-scale 3-wire cells with:
 *     RED   = C  (common)
 *     WHITE = +  (signal leg)
 *     BLACK = −  (signal leg)
 *
 *   The four cells are combined into one full bridge before reaching the HX711.
 *   Follow the same grouping shown in your scale wiring diagram:
 *
 *     RED / C wiring:
 *       Cell A (upper-left)   RED  ┐
 *       Cell B (upper-right)  RED  ├──────────────→  HX711 E+
 *       Cell C (lower-left)   RED  ┘
 *       Cell D (lower-right)  RED  ───────────────→  HX711 E−
 *
 *     BLACK / − wiring:
 *       Cell A (upper-left)   BLACK ──────────────→  HX711 A−
 *       Cell B (upper-right)  BLACK ┐
 *       Cell C (lower-left)   BLACK ┤
 *       Cell D (lower-right)  BLACK ┘
 *
 *     WHITE / + wiring:
 *       Cell A (upper-left)   WHITE ──────────────→  HX711 A+
 *       Cell B (upper-right)  WHITE ┐
 *       Cell C (lower-left)   WHITE ┤
 *       Cell D (lower-right)  WHITE ┘
 *
 *   Note: load-cell wire colours vary by manufacturer. This mapping matches
 *   the wiring diagram for this specific scale, not the generic RED/E+/BLACK/E−/
 *   WHITE/signal convention used by some other half-bridge sets.
 *
 * ── HX711 ↔ Wemos D1 Mini ────────────────────────────────────────────────────
 *
 *   HX711 VCC  →  3.3 V
 *   HX711 GND  →  GND
 *   HX711 DT   →  D6  (GPIO 12)
 *   HX711 SCK  →  D5  (GPIO 14)
 *
 * ── Button / LED ─────────────────────────────────────────────────────────────
 *
 *   D3 (GPIO 0)  = built-in FLASH button (active LOW)
 *     Short press  (<2 s)  → Tare (zero) the scale
 *     Long press   (>4 s)  → Erase WiFi credentials & restart into setup portal
 *
 *   D4 (GPIO 2) = built-in LED (active LOW)
 *     Fast blink  100 ms   → Connecting to WiFi or Blynk server
 *     Medium blink 500 ms  → Connected, idle
 *     Solid ON             → Sending data / taring
 *     2 quick flashes      → OTA ready after WiFi connect
 *
 * ── OTA Updates ────────────────────────────────────────────────────────────────
 *
 *   After the first USB flash, the device supports Arduino OTA updates over
 *   the local network.
 *
 *   Hostname:  keg-scale-<chipid>
 *   Password:  same as the configured auth token
 *   Web UI:    http://<device-ip>/         (status page)
 *              http://<device-ip>/update   (firmware upload)
 *
 * ── First-Time Setup ──────────────────────────────────────────────────────────
 *
 *   1. Flash this sketch to a Wemos D1 Mini.
 *   2. On first boot the device creates a WiFi AP called "KegScale-Setup".
 *   3. Connect to that AP (no password) and open http://192.168.4.1
 *   4. Fill in:
 *        WiFi SSID & password
 *        Plaato server host  (IP or hostname running open-plaato-keg)
 *        Plaato server port  (default 1234)
 *        Auth token          (32-character hex string from the server UI)
 *        Calibration factor  (optional, if already known)
 *        Max keg volume      (litres, e.g. 19 for a Corny keg)
 *        Beer name
 *   5. Save. The device reboots and connects automatically.
 *
 * ── Calibration ───────────────────────────────────────────────────────────────
 *
 *   Method A – via server UI (recommended):
 *     a. Make sure the scale is empty, then click "Tare" in the UI.
 *     b. Place a weight of known mass on the scale.
 *     c. Enter that mass (grams) in the "Calibrate" field and click Send.
 *
 *   Method B – via button:
 *     a. Remove everything from the scale.
 *     b. Short-press the FLASH button to tare.
 *     c. Place a known weight and note the raw value printed on Serial (115200).
 *     d. Set calibration factor via server UI or recalculate manually.
 *
 * ── Required Arduino Libraries (install via Library Manager) ──────────────────
 *
 *   1. WiFiManager          by tzapu              ≥ 2.0.17
 *   2. HX711 Arduino Library by Bogdan Necula      ≥ 0.7.5
 *
 *   Board: "LOLIN(WEMOS) D1 mini" – ESP8266 @ 80 MHz, 4 MB Flash
 */

// ─── Includes ─────────────────────────────────────────────────────────────────

#include <Arduino.h>
#include <ESP8266WiFi.h>
#include <ArduinoOTA.h>
#include <ESP8266WebServer.h>
#include <ESP8266HTTPUpdateServer.h>
#include <WiFiManager.h>          // tzapu/WiFiManager
#include <HX711.h>                // bogde/HX711
#include <Adafruit_BMP085.h>
#include <EEPROM.h>

// ─── Pin Definitions ──────────────────────────────────────────────────────────

#define HX711_DOUT_PIN   12   // D6
#define HX711_SCK_PIN    14   // D5
#define BUTTON_PIN        0   // D3 – built-in FLASH button (active LOW)
#define LED_PIN           2   // D4 – built-in LED (active LOW)

// ─── Compile-Time Constants ────────────────────────────────────────────────────

#define FW_VERSION          "1.0.6-units"

#define EEPROM_MAGIC        0xA6    // Sentinel to detect initialised config (bumped for temp_offset_c field)
#define EEPROM_SIZE         256

#define DEFAULT_SERVER_PORT 1234
#define SEND_INTERVAL_MS    10000   // Periodic data push (ms)
#define PING_INTERVAL_MS    30000   // Blynk keep-alive PING (ms)
#define RECONNECT_INTERVAL  5000    // Retry TCP connection (ms)
#define HX711_SAMPLES       10      // Readings averaged per weight sample
#define TARE_SAMPLES         5      // Keep short on ESP8266 to avoid WDT resets
#define CAL_SAMPLES          5      // Keep short on ESP8266 to avoid WDT resets
#define ZERO_DEADBAND_G      15.0f  // Clamp tiny drift to zero
#define POUR_DELTA_G        30      // g change to classify as "pouring"
#define POUR_SETTLE_MS      2000    // ms of stability before pour ends
#define POUR_ARM_DELAY_MS   5000    // Ignore pour detection briefly after tare/boot
#define BMP180_READ_INTERVAL_MS 5000

// ─── Blynk Command Codes ──────────────────────────────────────────────────────

#define BCMD_RESPONSE       0
#define BCMD_LOGIN          2
#define BCMD_PING           6
#define BCMD_HARDWARE_SYNC  16
#define BCMD_HARDWARE       20

// ─── Blynk Virtual Pin Numbers (as strings for body building) ────────────────
// Source: open-plaato-keg/lib/open_plaato_keg/plaato_data.ex

#define VP_PERCENT_LEFT    "48"
#define VP_IS_POURING      "49"
#define VP_AMOUNT_LEFT     "51"
#define VP_WEIGHT_RAW      "53"
#define VP_VOLUME_RAW      "54"
#define VP_POUR_VOL_RAW    "55"
#define VP_TEMPERATURE     "56"
#define VP_LAST_POUR       "59"
#define VP_TARE            "60"   // receive "1" → tare
#define VP_CALIBRATE       "61"   // receive current display weight → calibrate
#define VP_EMPTY_KEG       "62"   // receive "1" → capture current as empty
#define VP_BEER_NAME       "64"
#define VP_DATE            "67"
#define VP_TEMP_STRING     "69"
#define VP_UNIT            "71"   // "1"=metric  "2"=US
#define VP_WEIGHT_UNIT     "73"
#define VP_BEER_LEFT_UNIT  "74"
#define VP_MEASURE_UNIT    "75"   // "1"=weight  "2"=volume
#define VP_MAX_KEG_VOL     "76"   // current display volume
#define VP_TEMP_UNIT       "80"
#define VP_WIFI_RSSI       "81"
#define VP_VOLUME_UNIT     "82"
#define VP_FIRMWARE_VER    "93"
#define VP_TEMP_OFFSET     "52"   // receive offset in current display unit

// ─── Config Struct (persisted in EEPROM) ──────────────────────────────────────

struct Config {
  uint8_t  magic;
  char     server_host[64];
  uint16_t server_port;
  char     auth_token[33];     // 32-char hex + NUL
  float    cal_factor;         // HX711 scale factor (raw / gram)
  int32_t  tare_offset;        // HX711 raw offset after tare
  uint32_t empty_keg_g;        // Empty keg mass in grams
  uint32_t max_vol_ml;         // Full keg volume in mL
  char     beer_name[32];
  float    temp_offset_c;      // Temperature calibration offset in °C
  uint8_t  unit_system;        // 1=metric, 2=US/imperial
  uint8_t  measure_unit;       // 1=weight, 2=volume
};

// ─── Globals ──────────────────────────────────────────────────────────────────

HX711      scale;
Adafruit_BMP085 bmp180;
WiFiClient client;
ESP8266WebServer webServer(80);
ESP8266HTTPUpdateServer httpUpdater;
Config     cfg;

// Blynk state
uint16_t blynk_msg_id   = 1;
bool     blynk_authed   = false;

// Timing
uint32_t last_send_ms   = 0;
uint32_t last_ping_ms   = 0;
uint32_t last_reconnect = 0;

// Pour tracking
float    last_stable_g  = 0.0f;
float    last_weight_g  = 0.0f;
bool     is_pouring     = false;
uint32_t pour_start_ms  = 0;
float    pour_start_g   = 0.0f;
bool     have_baseline  = false;
bool     ota_in_progress = false;
uint32_t pour_arm_ms    = 0;
float    instant_weight_g = 0.0f;
bool     bmp180_present  = false;
float    bmp180_temp_c   = 0.0f;
uint32_t last_bmp180_ms  = 0;

// Deferred actions from the web UI to avoid doing long HX711 work inside HTTP handlers
bool     pending_tare           = false;
bool     pending_set_empty_keg  = false;
bool     pending_calibrate      = false;
float    pending_known_g        = 0.0f;

// LED
uint32_t led_last_ms    = 0;
bool     led_state      = false;

// Button
uint32_t btn_down_ms    = 0;
bool     btn_held       = false;

// WiFiManager custom parameters (initialised in setup after config load)
WiFiManagerParameter *p_server = nullptr;
WiFiManagerParameter *p_port   = nullptr;
WiFiManagerParameter *p_token  = nullptr;
WiFiManagerParameter *p_cal    = nullptr;
WiFiManagerParameter *p_keg    = nullptr;
WiFiManagerParameter *p_name   = nullptr;
WiFiManagerParameter *p_temp   = nullptr;

// ─── EEPROM Helpers ───────────────────────────────────────────────────────────

void loadConfig() {
  EEPROM.begin(EEPROM_SIZE);
  EEPROM.get(0, cfg);

  if (cfg.magic != EEPROM_MAGIC) {
    // First boot – apply defaults
    memset(&cfg, 0, sizeof(cfg));
    cfg.magic        = EEPROM_MAGIC;
    cfg.server_port  = DEFAULT_SERVER_PORT;
    cfg.cal_factor   = 1.0f;
    cfg.tare_offset  = 0;
    cfg.empty_keg_g  = 4000;    // ~4 kg typical Cornelius keg
    cfg.max_vol_ml   = 19000;   // 19 L Cornelius keg
    cfg.temp_offset_c = 0.0f;   // No temperature offset by default
    cfg.unit_system  = 1;
    cfg.measure_unit = 2;
    strncpy(cfg.beer_name, "Beer", sizeof(cfg.beer_name) - 1);
    saveConfig();
    Serial.println(F("[Config] EEPROM reset - defaults saved"));
  }

  if (cfg.unit_system != 1 && cfg.unit_system != 2) cfg.unit_system = 1;
  if (cfg.measure_unit != 1 && cfg.measure_unit != 2) cfg.measure_unit = 2;
}

void saveConfig() {
  EEPROM.put(0, cfg);
  EEPROM.commit();
}

// ─── LED Control ──────────────────────────────────────────────────────────────

void ledSolid(bool on) {
  digitalWrite(LED_PIN, on ? LOW : HIGH);   // active LOW
}

void ledBlink(uint32_t interval_ms) {
  uint32_t now = millis();
  if (now - led_last_ms >= interval_ms) {
    led_last_ms = now;
    led_state   = !led_state;
    digitalWrite(LED_PIN, led_state ? LOW : HIGH);
  }
}

void ledFlash(uint8_t times) {
  for (uint8_t i = 0; i < times; i++) {
    digitalWrite(LED_PIN, LOW);
    delay(80);
    yield();
    digitalWrite(LED_PIN, HIGH);
    delay(80);
    yield();
  }
}

// ─── OTA ──────────────────────────────────────────────────────────────────────

long readAverageRaw(uint8_t samples);

void logMemory(const char *tag) {
  Serial.printf("[Mem] %s free=%u frag=%u%% max=%u\n",
                tag,
                ESP.getFreeHeap(),
                ESP.getHeapFragmentation(),
                ESP.getMaxFreeBlockSize());
}

bool webAuthRequired() {
  return strlen(cfg.auth_token) > 0;
}

bool ensureWebAuth() {
  if (!webAuthRequired()) return true;
  if (webServer.authenticate("admin", cfg.auth_token)) return true;
  webServer.requestAuthentication();
  return false;
}

String jsonEscape(const String &s) {
  String out;
  out.reserve(s.length() + 8);
  for (size_t i = 0; i < s.length(); i++) {
    char c = s[i];
    if (c == '\\' || c == '"') out += '\\';
    out += c;
  }
  return out;
}

void handleWebState() {
  if (!ensureWebAuth()) return;

  float weight_g = readWeightGrams();
  long raw_adc = readAverageRaw(3);
  long raw_offset = scale.get_offset();
  long raw_delta = raw_adc - raw_offset;

  String json;
  json.reserve(420);
  json += F("{\"weight_g\":");
  json += String(weight_g, 1);
  json += F(",\"instant_weight_g\":");
  json += String(instant_weight_g, 1);
  json += F(",\"raw\":");
  json += String(raw_delta);
  json += F(",\"raw_adc\":");
  json += String(raw_adc);
  json += F(",\"raw_offset\":");
  json += String(raw_offset);
  json += F(",\"cal_factor\":");
  json += String(cfg.cal_factor, 4);
  json += F(",\"empty_keg_g\":");
  json += String(cfg.empty_keg_g);
  json += F(",\"max_vol_l\":");
  json += String((float)cfg.max_vol_ml / 1000.0f, 2);
  json += F(",\"temp_offset_c\":");
  json += String(cfg.temp_offset_c, 2);
  json += F(",\"temp_c\":");
  json += String(bmp180_temp_c, 1);
  json += F(",\"bmp180_present\":");
  json += bmp180_present ? F("true") : F("false");
  json += F(",\"beer_name\":\"");
  json += jsonEscape(String(cfg.beer_name));
  json += F("\",\"blynk\":\"");
  json += blynk_authed ? F("connected") : F("disconnected");
  json += F("\",\"ip\":\"");
  json += WiFi.localIP().toString();
  json += F("\",\"free_heap\":");
  json += String(ESP.getFreeHeap());
  json += F(",\"heap_frag\":");
  json += String(ESP.getHeapFragmentation());
  json += F(",\"max_block\":");
  json += String(ESP.getMaxFreeBlockSize());
  json += '}';

  webServer.send(200, "application/json", json);
}

void handleWebTare() {
  if (!ensureWebAuth()) return;
  pending_tare = true;
  webServer.send(202, "application/json", "{\"ok\":true,\"msg\":\"tare queued\"}");
}

void handleWebCalibrate() {
  if (!ensureWebAuth()) return;
  if (!webServer.hasArg("known_g")) {
    webServer.send(400, "application/json", "{\"ok\":false,\"msg\":\"known_g required\"}");
    return;
  }

  float known_g = webServer.arg("known_g").toFloat();
  if (known_g <= 0) {
    webServer.send(400, "application/json", "{\"ok\":false,\"msg\":\"known_g must be > 0\"}");
    return;
  }

  pending_known_g = known_g;
  pending_calibrate = true;
  webServer.send(202, "application/json", "{\"ok\":true,\"msg\":\"calibration queued\"}");
}

void handleWebSetEmptyKeg() {
  if (!ensureWebAuth()) return;

  if (webServer.hasArg("empty_g")) {
    float explicit_g = webServer.arg("empty_g").toFloat();
    if (explicit_g < 0) {
      webServer.send(400, "application/json", "{\"ok\":false,\"msg\":\"empty_g must be >= 0\"}");
      return;
    }
    cfg.empty_keg_g = (uint32_t)explicit_g;
    saveConfig();
    Serial.printf("[Scale] Empty keg weight set to %u g\n", cfg.empty_keg_g);
    webServer.send(200, "application/json", "{\"ok\":true}");
  } else {
    pending_set_empty_keg = true;
    webServer.send(202, "application/json", "{\"ok\":true,\"msg\":\"empty keg capture queued\"}");
  }
}

void handleWebSetTempOffset() {
  if (!ensureWebAuth()) return;
  if (!webServer.hasArg("offset_c")) {
    webServer.send(400, "application/json", "{\"ok\":false,\"msg\":\"offset_c required\"}");
    return;
  }

  float offset_c = webServer.arg("offset_c").toFloat();
  cfg.temp_offset_c = offset_c;
  saveConfig();
  Serial.printf("[Temp] Temperature offset set to %.2f °C\n", cfg.temp_offset_c);
  webServer.send(200, "application/json", "{\"ok\":true}");
}

void handleWebResetSetup() {
  if (!ensureWebAuth()) return;

  webServer.send(200, "application/json", "{\"ok\":true,\"msg\":\"resetting to setup mode\"}");
  delay(100);

  Serial.println(F("[Web] Resetting WiFi settings and rebooting to setup mode"));
  WiFiManager wm;
  wm.resetSettings();
  delay(250);
  ESP.restart();
}
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
void loop() {
  handleButton();
  ArduinoOTA.handle();
  webServer.handleClient();

  if (ota_in_progress) {
    return;
  }

  if (pending_tare) {
    pending_tare = false;
    doTare();
  }

  if (pending_calibrate) {
    pending_calibrate = false;
    doCalibrateWithKnownWeight(pending_known_g);
    pending_known_g = 0.0f;
  }

  if (pending_set_empty_keg) {
    pending_set_empty_keg = false;
    doSetEmptyKeg(readWeightGrams());
  }

  // ── WiFi watchdog ──
  if (WiFi.status() != WL_CONNECTED) {
    blynk_authed = false;
    client.stop();
    ledBlink(100);
    return;
  }

  // ── Blynk reconnect ──
  if (!client.connected()) {
    blynk_authed = false;
    ledBlink(250);
    if (millis() - last_reconnect >= RECONNECT_INTERVAL) {
      last_reconnect = millis();
      connectBlynk();
    }
    return;
  }

  // ── Process incoming packets ──
  blynkProcessIncoming();

  if (!blynk_authed) {
    ledBlink(250);
    return;
  }

  // ── Read weight ──
  float weight_g = readWeightGrams();
  updateTemperatureReading();
  bool  was_pouring = is_pouring;
  updatePourState(weight_g);

  // ── Push data ──
  uint32_t now = millis();
  bool pour_changed = (is_pouring != was_pouring);

  if (pour_changed || (now - last_send_ms >= SEND_INTERVAL_MS)) {
    last_send_ms = now;
    publishKegData(weight_g);
  }

  // ── Keep-alive PING ──
  if (now - last_ping_ms >= PING_INTERVAL_MS) {
    last_ping_ms = now;
    blynkSendRaw(BCMD_PING, nullptr, 0);
  }

  // Slow blink = connected & running
  ledBlink(500);
}

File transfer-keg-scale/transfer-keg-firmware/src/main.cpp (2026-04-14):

/*
 * Transfer Keg Firmware — Wemos D1 Mini (ESP8266)
 * ─────────────────────────────────────────────────
 * First boot (or no saved config):
 *   1. Broadcasts AP "TransferScale-Setup"  (pw: "scaleme")
 *   2. Connect → browse to 192.168.4.1
 *   3. Configure WiFi, server, and optionally run the Calibration wizard
 *   4. Save & Reboot — device connects as STA
 *
 * Re-enter setup: hold D3/FLASH at boot for 3 s, or send 'x' via Serial.
 *
 * Calibration API (used by the portal wizard):
 *   POST /cal/tare          — zero the scale (nothing on platform)
 *   POST /cal/measure       — body: {"knownKg": 10.0}
 *                             returns {"raw": 123456, "factor": -432.1, "readKg": 10.01}
 *   POST /cal/apply         — body: {"factor": -432.1}
 *                             writes factor to cfg and saves EEPROM
 */

#include <Arduino.h>
#include <Wire.h>
#include <EEPROM.h>
#include <ESP8266WiFi.h>
#include <ESP8266WebServer.h>
#include <ESP8266HTTPClient.h>
#include <DNSServer.h>
#include <WiFiClient.h>
#include <HX711.h>
#include <Adafruit_GFX.h>
#include <Adafruit_SH110X.h>

// ─────────────────────────────────────────────
//  HARDWARE CONSTANTS
// ─────────────────────────────────────────────
#define HX711_DOUT_PIN   14   // D5
#define HX711_SCK_PIN    12   // D6
#define OLED_SDA_PIN      4   // D2
#define OLED_SCL_PIN      5   // D1
#define SETUP_BTN_PIN     0   // D3 / GPIO0 (FLASH button — active LOW)
#define TARE_BTN_PIN     13   // D7 — momentary button to GND, active LOW

#define SCREEN_WIDTH    128
#define SCREEN_HEIGHT    64
#define OLED_RESET       -1
#define OLED_ADDRESS   0x3C

#define WEIGH_INTERVAL_MS    1000
#define POST_INTERVAL_MS     5000
#define GET_INTERVAL_MS     30000
#define SCALE_SAMPLES           5
#define CAL_SAMPLES            20   // more samples for calibration accuracy

// ─────────────────────────────────────────────
//  AP / PORTAL CONSTANTS
// ─────────────────────────────────────────────
#define AP_SSID     "TransferScale-Setup"
#define AP_PASSWORD "scaleme"
#define DNS_PORT    53
static const IPAddress AP_IP(192, 168, 4, 1);

// ─────────────────────────────────────────────
//  EEPROM
// ─────────────────────────────────────────────
#define EEPROM_SIZE       512
#define EEPROM_MAGIC_VAL  0xA5
#define EEPROM_ADDR_MAGIC   0
#define EEPROM_ADDR_CFG     1

struct Config {
    char  wifiSSID[64];
    char  wifiPassword[64];
    char  serverBaseURL[128];
    char  scaleID[32];
    float calibrationFactor;
    float defaultEmptyKg;
    float defaultTargetKg;
};

Config cfg;

// ─────────────────────────────────────────────
//  OBJECTS
// ─────────────────────────────────────────────
Adafruit_SH1106G display(SCREEN_WIDTH, SCREEN_HEIGHT, &Wire, OLED_RESET);
HX711            scale;
WiFiClient       wifiClient;
HTTPClient       http;
ESP8266WebServer server(80);
DNSServer        dnsServer;

// ─────────────────────────────────────────────
//  RUNTIME STATE
// ─────────────────────────────────────────────
float         currentWeightKg = 0.0f;
float         emptyKegKg      = 3.8f;
float         targetKg        = 12.5f;
unsigned long lastWeighTime   = 0;
unsigned long lastPostTime    = 0;
unsigned long lastGetTime     = 0;
bool          wifiConnected   = false;
bool          scaleReady      = false;
bool          calTareDone     = false;   // tracks wizard step state
float         calPendingFactor = 0.0f;  // factor calculated but not yet applied

// ─────────────────────────────────────────────
//  EEPROM HELPERS
// ─────────────────────────────────────────────
void saveConfig() {
    EEPROM.begin(EEPROM_SIZE);
    EEPROM.write(EEPROM_ADDR_MAGIC, EEPROM_MAGIC_VAL);
    const uint8_t* p = (const uint8_t*)&cfg;
    for (size_t i = 0; i < sizeof(cfg); i++)
        EEPROM.write(EEPROM_ADDR_CFG + i, p[i]);
    EEPROM.commit();
    EEPROM.end();
    Serial.println("[EEPROM] saved");
}

bool loadConfig() {
    EEPROM.begin(EEPROM_SIZE);
    if (EEPROM.read(EEPROM_ADDR_MAGIC) != EEPROM_MAGIC_VAL) { EEPROM.end(); return false; }
    uint8_t* p = (uint8_t*)&cfg;
    for (size_t i = 0; i < sizeof(cfg); i++)
        p[i] = EEPROM.read(EEPROM_ADDR_CFG + i);
    EEPROM.end();
    Serial.println("[EEPROM] loaded");
    return true;
}

void setDefaultConfig() {
    strncpy(cfg.wifiSSID,      "",                          sizeof(cfg.wifiSSID)      - 1);
    strncpy(cfg.wifiPassword,  "",                          sizeof(cfg.wifiPassword)  - 1);
    strncpy(cfg.serverBaseURL, "http://192.168.1.100:3000", sizeof(cfg.serverBaseURL) - 1);
    strncpy(cfg.scaleID,       "scale1",                   sizeof(cfg.scaleID)       - 1);
    cfg.calibrationFactor = -430.0f;
    cfg.defaultEmptyKg    = 4.028f;
    cfg.defaultTargetKg   = 19.15f;
}

// ─────────────────────────────────────────────
//  OLED HELPERS
// ─────────────────────────────────────────────
void drawProgressBar(int x, int y, int w, int h, float pct) {
    display.drawRect(x, y, w, h, SH110X_WHITE);
    int fill = (int)((float)(w - 2) * constrain(pct, 0.0f, 1.0f));
    if (fill > 0) display.fillRect(x + 1, y + 1, fill, h - 2, SH110X_WHITE);
}

void showMessage(const char* l1, const char* l2 = nullptr, const char* l3 = nullptr) {
    display.clearDisplay();
    display.setTextSize(1);
    display.setTextColor(SH110X_WHITE);
    display.setCursor(0, 10); display.println(l1);
    if (l2) { display.setCursor(0, 26); display.println(l2); }
    if (l3) { display.setCursor(0, 42); display.println(l3); }
    display.display();
}

void renderSetupScreen() {
    display.clearDisplay();
    display.setTextSize(1);
    display.setTextColor(SH110X_WHITE);
    display.setCursor(0,  0); display.println(F("=== SETUP MODE ==="));
    display.setCursor(0, 14); display.println(F("WiFi: TransferScale"));
    display.setCursor(0, 24); display.println(F("      -Setup"));
    display.setCursor(0, 36); display.println(F("Pass: scaleme"));
    display.setCursor(0, 50); display.println(F("http://192.168.4.1"));
    display.display();
}
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

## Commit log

2026-03-06 Add keg scale 3D models, assets, and firmware
    Add complete Ball Lock keg scale project assets: 3MF, multiple STL and SKP CAD files under files/, product images under images/, project README and LICENSE, and Plaato firmware binary under "scale fi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
    [BottomPinlock2.stl, Bottom_BallLock100sided.stl, Bottom_fixed.stl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]
2026-04-04 Add Buy Me A Coffee button to README
2026-04-07 Add bottom cover STL and generator script for HX711 load cell installation
    Adds a 210x210 mm bottom cover designed to fit the existing keg scale top
    plate. Includes 4 round 60mm dia feet at corners, each with a 35x35x12mm
    pocket for the 50kg parallel-beam load cells, M4 mounting holes at 28mm
    C-C, and a wire access hole per foot. Generated via Python/trimesh/manifold3d.
    [keg_scale_bottom_cover.stl]
2026-04-07 Redesign bottom cover: upward feet contact load cells mounted in top housing
    Load cells mount in the top of the scale body pointing down, so the bottom
    cover now has 4 upward-pointing 16mm dia cylindrical feet at each corner
    (32,32 / 178,32 / 32,178 / 178,178) that pass through the 18mm holes in
    the scale body bottom and contact the load cell free ends from below.
    Dome tip added for self-centering. Rubber-foot recesses on underside.
    [keg_scale_bottom_cover.stl]
2026-04-08 Match scale body corner radius (32 mm) on bottom cover
    The existing scale body has 32 mm rounded corners. Switched the cover
    plate from a plain box to a shapely-extruded rounded rectangle with the
    same 32 mm corner radius so the cover aligns flush with the scale body.
    [keg_scale_bottom_cover.stl]
2026-04-08 Split bottom cover into two separate STL files
    - keg_scale_bottom_cover.stl: cover plate only (210x210x5mm, 32mm corners,
    16.5mm holes for feet, rubber-foot recesses on underside)
    - keg_scale_feet.stl: 4 separate feet laid out for printing (16mm dia x
    15mm tall + 1mm dome tip, 2x2 grid)
    [keg_scale_bottom_cover.stl, keg_scale_feet.stl]
2026-04-09 Redesign feet as T-shape with locating pins for snug load cell fit
    Scale body corner holes are 21.5 mm dia. Feet are now T-shaped:
    - Stem: 20 mm dia x 22 mm (snug in 21.5 mm holes, dropped in from top)
    - Cap: 36 mm dia x 3 mm (wider than hole, retained inside scale body)
    - 2x locating pins on cap top: 3 mm dia x 4 mm at 28 mm C-C, index
    into the load cell free-end M4 mounting holes for a positive snug fit
    Cover plate holes updated to 21.5 mm to match body holes.
    [keg_scale_bottom_cover.stl, keg_scale_feet.stl]
2026-04-09 Add 8.25 mm side wall to bottom cover for load cell clearance
    Load cells hang 5.25 mm below the scale body; feet caps are 3 mm thick,
    total 8.25 mm. Added a 3 mm thick perimeter wall that height around the
    inside edge of the cover, creating a cavity that accommodates both with
    concentric 29 mm inner corner radius matching the 32 mm outer profile.
    [keg_scale_bottom_cover.stl]
2026-04-09 Add /save-design slash command for STL generation and commit workflow
    Encodes the full design iteration workflow: run generator, copy STLs
    into repo, stage, commit with descriptive message, and push.
2026-04-10 Fix corner radius to 12 mm and move foot holes to 51 mm from corner
    Corner radius was wrong (32 mm was the load cell boss centre, not the
    outer profile). Arc-fit of the scale body STL confirms 12 mm. Also
    fixed rounded_rect_extrusion to use circle+strip union instead of
    convex_hull so corners are true arcs, not chord approximations.
    Foot hole centres moved from 32 mm to 51 mm from each corner edge.
    [keg_scale_bottom_cover.stl]
2026-04-10 Move foot hole centers to 69 mm from origin (51 mm from physical corner tip)
    Previous position (51,51) placed holes 18 mm short of the load cell
    mounting holes in the scale body. Overlaying STLs confirmed the offset;
    new centers at (69,69),(141,69),(69,141),(141,141) align correctly.
    [keg_scale_bottom_cover.stl]
2026-04-10 Move foot hole centers to 33 mm from origin (closer to corners)
    Testing 33 mm position: centers at (33,33),(177,33),(33,177),(177,177).
    [keg_scale_bottom_cover.stl]
2026-04-10 Move foot hole centers to 39 mm from origin
    Testing 39 mm position: centers at (39,39),(171,39),(39,171),(171,171).
    [keg_scale_bottom_cover.stl]
2026-04-10 Shorten foot stem to 14 mm, remove pins, add 24x10x2 mm cap recess
    - Stem reduced from 22 mm to 14 mm based on test fit
    - Removed locating pins (no longer needed)
    - Added 24 mm x 10 mm x 2 mm deep rectangular recess centred on cap
    top to clear the raised boss on the load cell free end
    [keg_scale_feet.stl]
2026-04-10 Increase cap recess depth from 2 mm to 5 mm
    Deeper pocket gives more clearance for the load cell raised boss.
    [keg_scale_feet.stl]
2026-04-10 Move cover holes to 43 mm; replace round cap with 28x14 mm rect cap + 5 mm pocket
    - Foot holes moved from 39 mm to 43 mm from origin (4 mm further from corner)
    - Cap changed from 36 mm dia cylinder to 28x14 mm rectangular box sized
    to match the load cell boss footprint (glued in place)
    - Pocket remains 24x10 mm but deepened recess now fully contained in the
    3 mm cap + pocket extends up through cap (5 mm deep total into cap face)
    [keg_scale_bottom_cover.stl, keg_scale_feet.stl]
2026-04-10 Open-end the cap slot so wire cement can't catch on pocket walls
    Changed closed 24x10 pocket to a 30x10 open-ended slot that punches
    through both ends of the 28 mm cap. The boss seats in the centre of
    the slot while strain gauge wires and cement exit freely out either
    end, ensuring the foot transfers weight flush to the boss.
    [keg_scale_feet.stl]
2026-04-10 Open slot sides so strain gauge wires exit along the 24 mm axis
    Wires run along the 24 mm dimension and exit from the side walls.
    Changed slot from open-ended (30x10) to open-sided (24x16) — slot now
    punches through both long sides of the 14 mm cap while the 28 mm end
    walls retain the boss position. Wires clear freely out either side.
    [keg_scale_feet.stl]
2026-04-10 Remove cap from feet; add boss pocket sized to GML692 datasheet
    - Cap removed entirely — foot is now a plain 20mm dia x 14mm stem
    - Pocket (15 x 8.5 x 3 mm deep) cut into stem top to seat over the
    GML692 boss (14 x 7.5 x 2.5 mm) with 0.5 mm clearance each side
    - Foot is glued to boss; no retention cap needed
    [keg_scale_feet.stl]
2026-04-10 Update stem pocket to caliper-measured 24x10x3 mm boss dimensions
    10 mm width confirmed correct with calipers. 24 mm length exceeds the
    20 mm stem diameter so the slot breaks through both ends of the stem,
    forming an open cradle — boss is held by the 10 mm side walls with
    5 mm of stem wall each side. Wires exit freely through the open ends.
    [keg_scale_feet.stl]
2026-04-10 Reduce stem pocket depth to 2 mm
    [keg_scale_feet.stl]
2026-04-11 Move foot holes 3 mm closer to corners (43 mm -> 40 mm)
    [keg_scale_bottom_cover.stl]
2026-04-11 Restore T-shaped foot: 36 mm cap + 20 mm stem + 24x10x2 mm pocket
    Brought back the original cap (36 mm dia x 3 mm) on top of the 14 mm
    stem. Pocket (24 x 10 x 2 mm deep) cut into cap top seats over the
    caliper-measured GML692 boss; foot glued in place.
    [keg_scale_feet.stl]
2026-04-11 Remove pocket from cap; extend stem from 14 mm to 18 mm
    [keg_scale_feet.stl]
2026-04-14 Add ESP8266 firmware for open-plaato-keg compatible keg scale
    Arduino sketch for Wemos D1 Mini + HX711 + 4x 50kg half-bridge load
    cells. Implements the Blynk binary TCP protocol to report weight,
    volume, and pour events to the open-plaato-keg server.
2026-04-18 Cleaned up folders
    Cleaned repo org of folders and files
    [BottomPinlock2.stl, Bottom_BallLock100sided.stl, Bottom_fixed.stl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]
2026-04-18 Create Wiring info.jpg
    added wiring info
2026-04-26 fix: persist scale display units
    [open_keg_scale.ino]
